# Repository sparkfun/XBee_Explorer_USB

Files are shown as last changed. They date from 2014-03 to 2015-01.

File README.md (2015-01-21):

SparkFun XBee Explorer USB
==========================

SparkFun XBee Explorer USB

[*SparkFun XBee Explorer USB (WRL-11812)*](https://www.sparkfun.com/products/11812)

This is a simple to use, USB to serial base unit for the Digi XBee line. 
This unit works with all XBee modules including the Series 1 and Series 2.5, standard and Pro version. 
Plug the unit into the XBee Explorer, attach a mini USB cable, 
and you will have direct access to the serial and programming pins on the XBee unit.
It has an FT231X USB-to-serial converter on board. 

Repository Contents
-------------------

* **/Hardware** - All Eagle design files (.brd, .sch)
* **/Production** - Test bed files and production panel files

Product Versions
----------------
* [WRL-08687](https://www.sparkfun.com/products/retired/8687)- Hardware version 1.5, with FT232 USB-to-serial converter. Retired

Version History
---------------
* [V_2.1](https://github.com/sparkfun/XBee_Explorer_USB/tree/V_2.1) - GitHub files version 2.1
* [V_1.5](https://github.com/sparkfun/XBee_Explorer_USB/tree/V_1.5) -- GitHub files version 1.5

License Information
-------------------
The hardware is released under [Creative Commons ShareAlike 4.0 International](https://creativecommons.org/licenses/by-sa/4.0/).

Distributed as-is; no warranty is given.

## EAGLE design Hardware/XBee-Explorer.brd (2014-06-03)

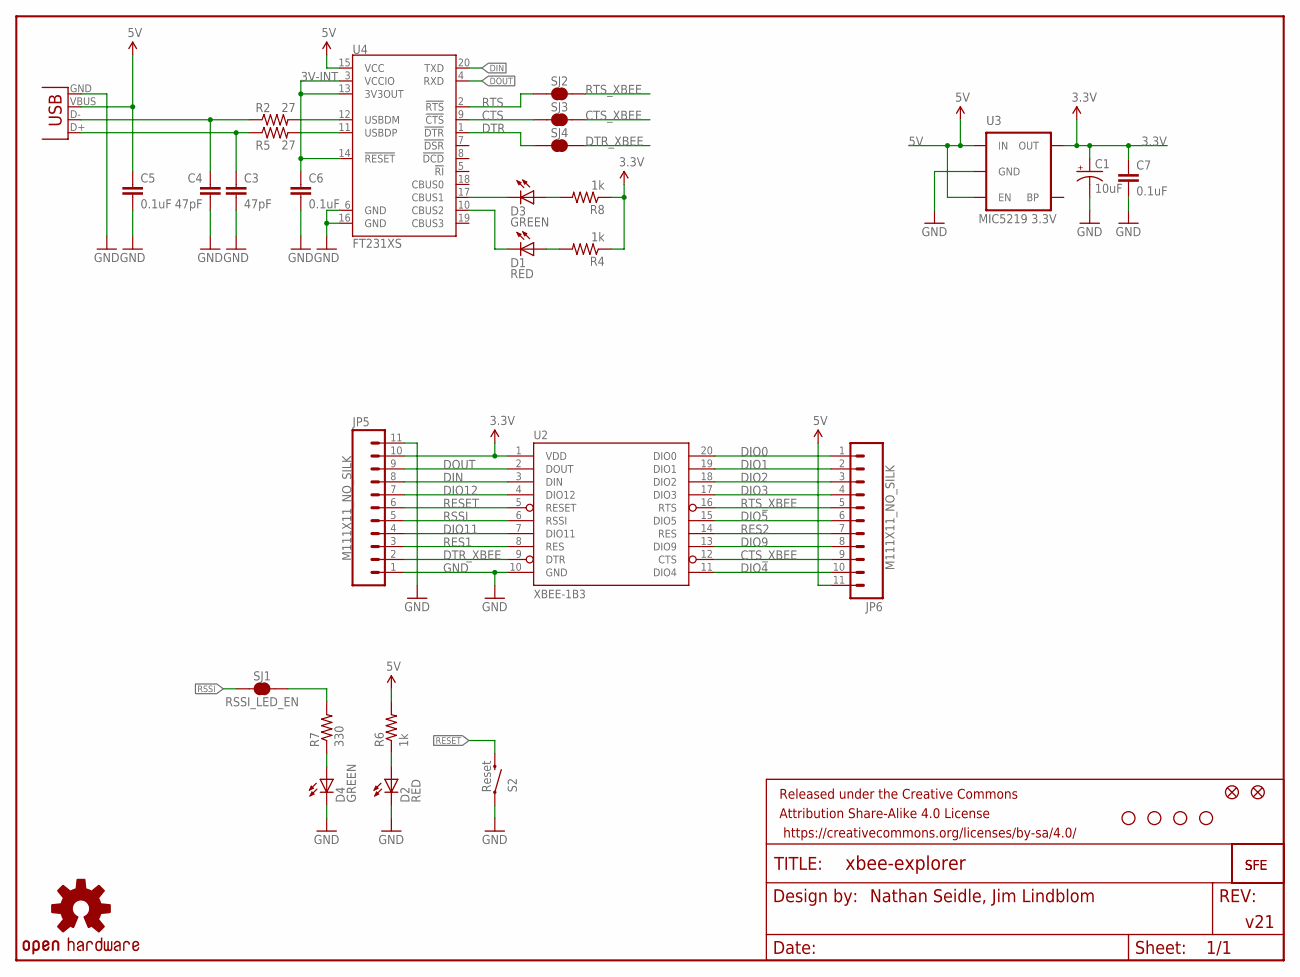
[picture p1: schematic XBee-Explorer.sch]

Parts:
C1: 10uF; EIA3216
C3, C4: 47pF; 0603-CAP
C5, C6, C7: 0.1uF; 0603-CAP
D1, D2: RED; LED-0603
D3, D4: GREEN; LED-0603
FRAME1: FRAME-LETTER; CREATIVE_COMMONS
JP1, JP4: FIDUCIAL1X2; FIDUCIAL-1X2
JP5, JP6: M111X11_NO_SILK; 1X11_NO_SILK
LOGO1: OSHW-LOGOS; OSHW-LOGO-S
R2, R5: 27; 0603-RES
R4, R6, R8: 1k; 0603-RES
R7: 330; 0603-RES
S2: Reset; TACTILE_SWITCH_SMD
SJ1: RSSI_LED_EN; SJ_2S-TRACE
SJ2: CTS_EN; SJ_2S-TRACE
SJ3: RTS_EN; SJ_2S-TRACE
SJ4: DTR; SJ_2S-TRACE
U2: XBEE-1B3; XBEE-SMD
U3: MIC5219 3.3V; SOT23-5
U4: FT231XS; SSOP20_L
U$1: LOGO-SFESK; SFE-LOGO-FLAME
U$4: LOGO-SFENEW; SFE-NEW-WEBLOGO
U$5, U$9, U$10, U$11: STAND-OFF
X1: USBSMD; USB-MINIB

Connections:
3.3V: C1.A (+), C7.1, JP5.10, R4.1, R8.1, U2.1 (VDD), U3.5 (OUT)
3V-INT: C6.1, U4.3 (VCCIO), U4.13 (3V3OUT), U4.14 (!RESET)
5V: C5.1, JP6.11, R6.2, U3.1 (IN), U3.3 (EN), U4.15 (VCC), X1.VBUS
CTS: SJ3.1, U4.9 (!CTS)
CTS_XBEE: JP6.9, SJ3.2, U2.12 (CTS)
DIN: JP5.8, U2.3 (DIN), U4.20 (TXD)
DIO0: JP6.1, U2.20 (DIO0)
DIO1: JP6.2, U2.19 (DIO1)
DIO2: JP6.3, U2.18 (DIO2)
DIO3: JP6.4, U2.17 (DIO3)
DIO4: JP6.10, U2.11 (DIO4)
DIO5: JP6.6, U2.15 (DIO5)
DIO9: JP6.8, U2.13 (DIO9)
DIO11: JP5.4, U2.7 (DIO11)
DIO12: JP5.7, U2.4 (DIO12)
DOUT: JP5.9, U2.2 (DOUT), U4.4 (RXD)
DTR: SJ4.1, U4.1 (!DTR)
DTR_XBEE: JP5.2, SJ4.2, U2.9 (DTR)
GND: C1.C (-), C3.2, C4.2, C5.2, C6.2, C7.2, D2.C, D4.C, JP5.1, JP5.11, S2.1, U2.10 (GND), U3.2 (GND), U4.6 (GND), U4.16 (GND), X1.GND
unnamed: D1.A, R4.2
unnamed: D4.A, R7.1
unnamed: C3.1, R5.1, X1.D+
unnamed: D3.A, R8.2
unnamed: C4.1, R2.1, X1.D-
unnamed: D3.C, U4.17 (CBUS1)
unnamed: R5.2, U4.11 (USBDP)
unnamed: R2.2, U4.12 (USBDM)
unnamed: R7.2, SJ1.2
unnamed: D2.A, R6.1
RES1: JP5.3, U2.8 (RES)
RES2: JP6.7, U2.14 (RES)
RESET: JP5.6, S2.3 (2), U2.5 (RESET)
RSSI: JP5.5, SJ1.1, U2.6 (RSSI)
RTS: SJ2.1, U4.2 (!RTS)
RTS_XBEE: JP6.5, SJ2.2, U2.16 (RTS)
TXLED: D1.C, U4.10 (CBUS2)

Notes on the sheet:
Nathan Seidle, Jim Lindblom
v21

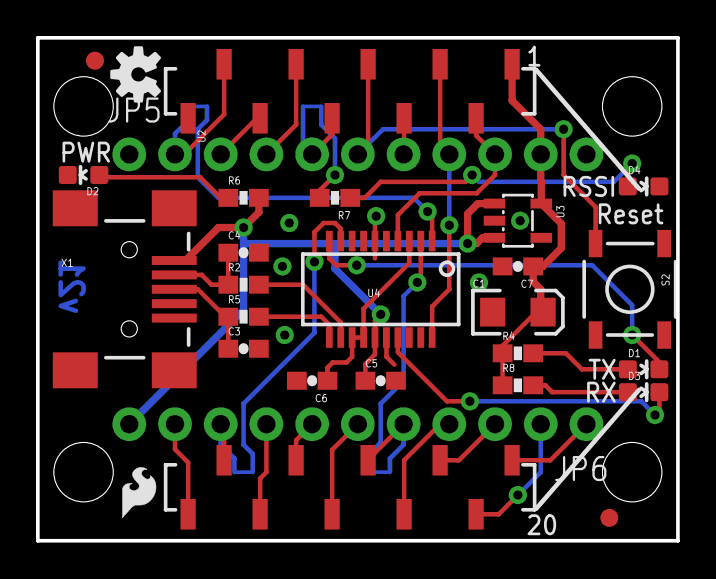
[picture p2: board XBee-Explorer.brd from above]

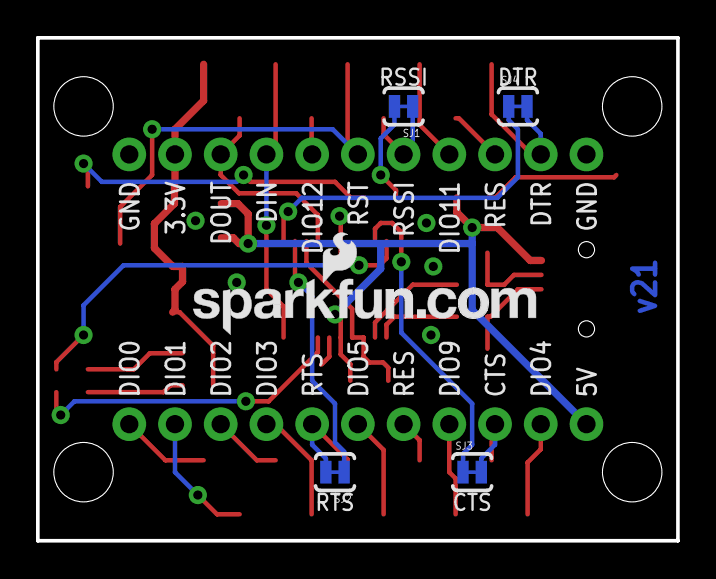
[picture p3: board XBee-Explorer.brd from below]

Board: 2 copper layers, 35.6 x 27.9 mm, 37 parts (5 on the bottom side), 36 nets.

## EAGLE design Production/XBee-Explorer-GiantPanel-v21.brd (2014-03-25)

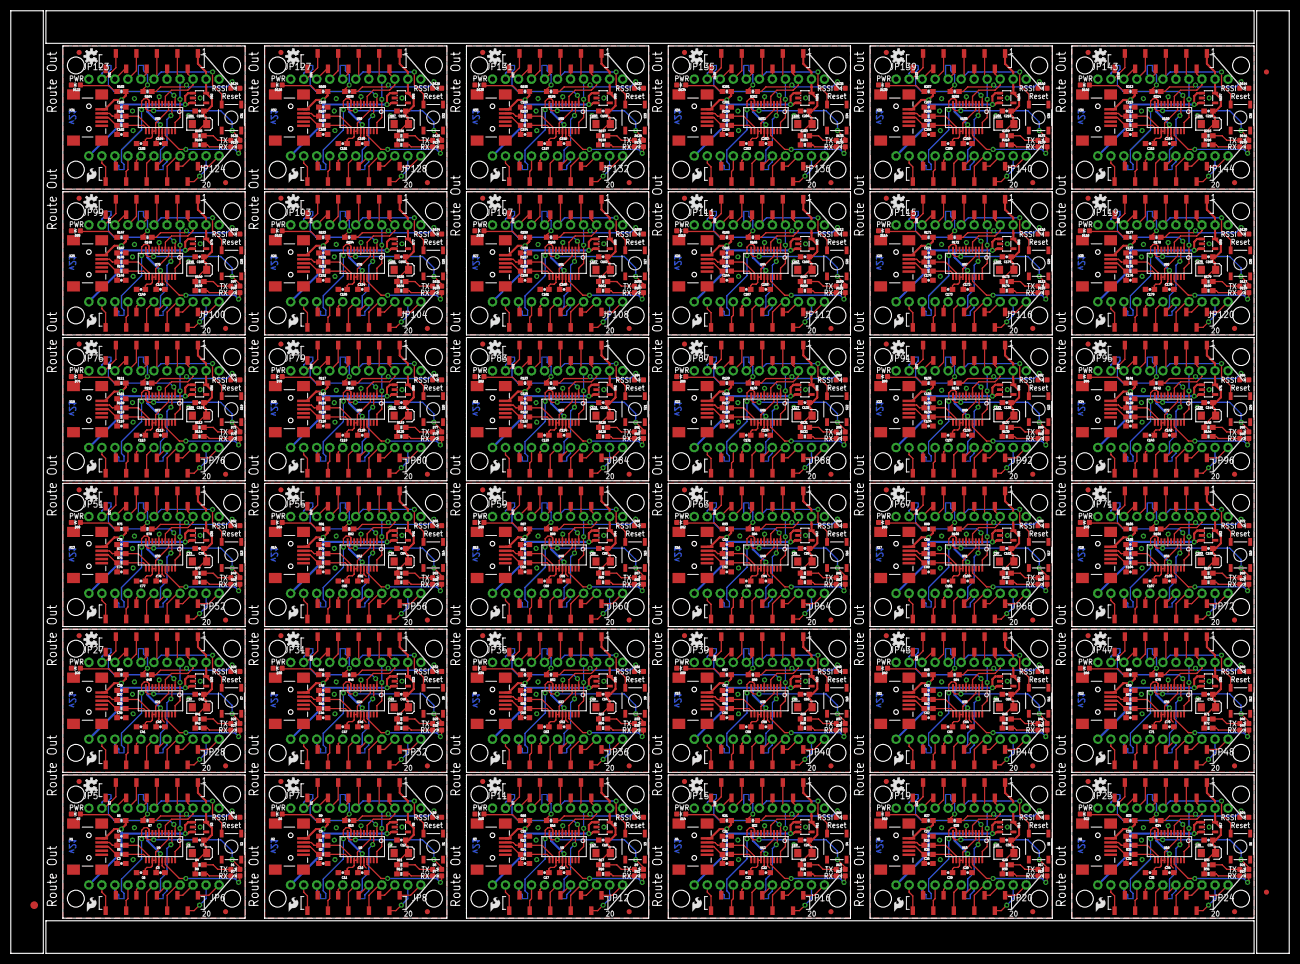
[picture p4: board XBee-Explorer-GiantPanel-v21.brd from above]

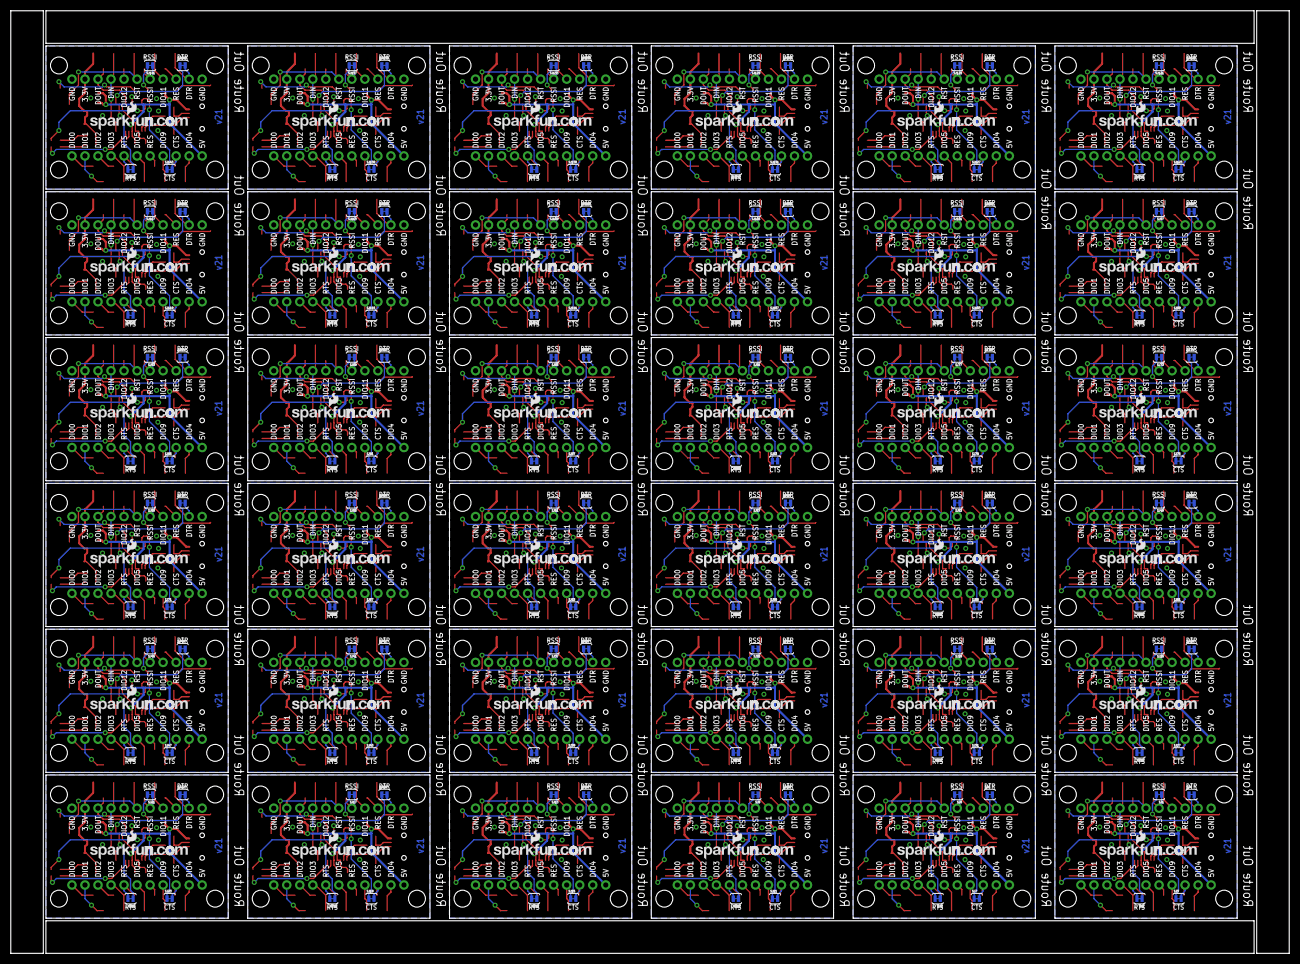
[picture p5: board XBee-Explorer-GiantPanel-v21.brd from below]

Board: 2 copper layers, 249.4 x 183.9 mm, 1299 parts (180 on the bottom side), 1296 nets.

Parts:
C1, C2, C13, C19, C25, C31, C37, C43, C49, C55, C61, C67, C73, C79, C85, C91, C97, C103, C109, C115, C121, C127, C133, C139, C145, C151, C157, C163, C169, C175, C181, C187, C193, C199, C205, C211: 10uF; EIA3216
C3, C4, C8, C9, C14, C15, C20, C21, C26, C27, C32, C33, C38, C39, C44, C45, C50, C51, C56, C57, C62, C63, C68, C69, C74, C75, C80, C81, C86, C87, C92, C93, C98, C99, C104, C105, C110, C111, C116, C117, C122, C123, C128, C129, C134, C135, C140, C141, C146, C147, C152, C153, C158, C159, C164, C165, C170, C171, C176, C177, C182, C183, C188, C189, C194, C195, C200, C201, C206, C207, C212, C213: 47pF; 0603-CAP
C5, C6, C7, C10, C11, C12, C16, C17, C18, C22, C23, C24, C28, C29, C30, C34, C35, C36, C40, C41, C42, C46, C47, C48, C52, C53, C54, C58, C59, C60, C64, C65, C66, C70, C71, C72, C76, C77, C78, C82, C83, C84, C88, C89, C90, C94, C95, C96, C100, C101, C102, C106, C107, C108, C112, C113, C114, C118, C119, C120, C124, C125, C126, C130, C131, C132, C136, C137, C138, C142, C143, C144, C148, C149, C150, C154, C155, C156, C160, C161, C162, C166, C167, C168, C172, C173, C174, C178, C179, C180, C184, C185, C186, C190, C191, C192, C196, C197, C198, C202, C203, C204, C208, C209, C210, C214, C215, C216: 0.1uF; 0603-CAP
D1, D2, D5, D6, D9, D10, D13, D14, D17, D18, D21, D22, D25, D26, D29, D30, D33, D34, D37, D38, D41, D42, D45, D46, D49, D50, D53, D54, D57, D58, D61, D62, D65, D66, D69, D70, D73, D74, D77, D78, D81, D82, D85, D86, D89, D90, D93, D94, D97, D98, D101, D102, D105, D106, D109, D110, D113, D114, D117, D118, D121, D122, D125, D126, D129, D130, D133, D134, D137, D138, D141, D142: RED; LED-0603
D3, D4, D7, D8, D11, D12, D15, D16, D19, D20, D23, D24, D27, D28, D31, D32, D35, D36, D39, D40, D43, D44, D47, D48, D51, D52, D55, D56, D59, D60, D63, D64, D67, D68, D71, D72, D75, D76, D79, D80, D83, D84, D87, D88, D91, D92, D95, D96, D99, D100, D103, D104, D107, D108, D111, D112, D115, D116, D119, D120, D123, D124, D127, D128, D131, D132, D135, D136, D139, D140, D143, D144: GREEN; LED-0603
E$1: FIDUCIAL-1.5X3
E$5, E$7: FIDUCIAL-1X2
JP1, JP2, JP3, JP4, JP9, JP10, JP13, JP14, JP17, JP18, JP21, JP22, JP25, JP26, JP29, JP30, JP33, JP34, JP37, JP38, JP41, JP42, JP45, JP46, JP49, JP50, JP53, JP54, JP57, JP58, JP61, JP62, JP65, JP66, JP69, JP70, JP73, JP74, JP77, JP78, JP81, JP82, JP85, JP86, JP89, JP90, JP93, JP94, JP97, JP98, JP101, JP102, JP105, JP106, JP109, JP110, JP113, JP114, JP117, JP118, JP121, JP122, JP125, JP126, JP129, JP130, JP133, JP134, JP137, JP138, JP141, JP142: FIDUCIAL1X2; FIDUCIAL-1X2
JP5, JP6, JP7, JP8, JP11, JP12, JP15, JP16, JP19, JP20, JP23, JP24, JP27, JP28, JP31, JP32, JP35, JP36, JP39, JP40, JP43, JP44, JP47, JP48, JP51, JP52, JP55, JP56, JP59, JP60, JP63, JP64, JP67, JP68, JP71, JP72, JP75, JP76, JP79, JP80, JP83, JP84, JP87, JP88, JP91, JP92, JP95, JP96, JP99, JP100, JP103, JP104, JP107, JP108, JP111, JP112, JP115, JP116, JP119, JP120, JP123, JP124, JP127, JP128, JP131, JP132, JP135, JP136, JP139, JP140, JP143, JP144: M111X11_NO_SILK; 1X11_NO_SILK
LOGO1, LOGO2, LOGO3, LOGO4, LOGO5, LOGO6, LOGO7, LOGO8, LOGO9, LOGO10, LOGO11, LOGO12, LOGO13, LOGO14, LOGO15, LOGO16, LOGO17, LOGO18, LOGO19, LOGO20, LOGO21, LOGO22, LOGO23, LOGO24, LOGO25, LOGO26, LOGO27, LOGO28, LOGO29, LOGO30, LOGO31, LOGO32, LOGO33, LOGO34, LOGO35, LOGO36: OSHW-LOGOS; OSHW-LOGO-S
R1, R2, R3, R5, R13, R14, R19, R20, R25, R26, R31, R32, R37, R38, R43, R44, R49, R50, R55, R56, R61, R62, R67, R68, R73, R74, R79, R80, R85, R86, R91, R92, R97, R98, R103, R104, R109, R110, R115, R116, R121, R122, R127, R128, R133, R134, R139, R140, R145, R146, R151, R152, R157, R158, R163, R164, R169, R170, R175, R176, R181, R182, R187, R188, R193, R194, R199, R200, R205, R206, R211, R212: 27; 0603-RES
R4, R6, R8, R9, R11, R12, R15, R17, R18, R21, R23, R24, R27, R29, R30, R33, R35, R36, R39, R41, R42, R45, R47, R48, R51, R53, R54, R57, R59, R60, R63, R65, R66, R69, R71, R72, R75, R77, R78, R81, R83, R84, R87, R89, R90, R93, R95, R96, R99, R101, R102, R105, R107, R108, R111, R113, R114, R117, R119, R120, R123, R125, R126, R129, R131, R132, R135, R137, R138, R141, R143, R144, R147, R149, R150, R153, R155, R156, R159, R161, R162, R165, R167, R168, R171, R173, R174, R177, R179, R180, R183, R185, R186, R189, R191, R192, R195, R197, R198, R201, R203, R204, R207, R209, R210, R213, R215, R216: 1k; 0603-RES
R7, R10, R16, R22, R28, R34, R40, R46, R52, R58, R64, R70, R76, R82, R88, R94, R100, R106, R112, R118, R124, R130, R136, R142, R148, R154, R160, R166, R172, R178, R184, R190, R196, R202, R208, R214: 330; 0603-RES
S1, S2, S3, S4, S5, S6, S7, S8, S9, S10, S11, S12, S13, S14, S15, S16, S17, S18, S19, S20, S21, S22, S23, S24, S25, S26, S27, S28, S29, S30, S31, S32, S33, S34, S35, S36: Reset; TACTILE_SWITCH_SMD
SJ1, SJ5, SJ9, SJ13, SJ17, SJ21, SJ25, SJ29, SJ33, SJ37, SJ41, SJ45, SJ49, SJ53, SJ57, SJ61, SJ65, SJ69, SJ73, SJ77, SJ81, SJ85, SJ89, SJ93, SJ97, SJ101, SJ105, SJ109, SJ113, SJ117, SJ121, SJ125, SJ129, SJ133, SJ137, SJ141: RSSI_LED_EN; SJ_2S-TRACE
SJ2, SJ8, SJ12, SJ16, SJ20, SJ24, SJ28, SJ32, SJ36, SJ40, SJ44, SJ48, SJ52, SJ56, SJ60, SJ64, SJ68, SJ72, SJ76, SJ80, SJ84, SJ88, SJ92, SJ96, SJ100, SJ104, SJ108, SJ112, SJ116, SJ120, SJ124, SJ128, SJ132, SJ136, SJ140, SJ144: CTS_EN; SJ_2S-TRACE
SJ3, SJ7, SJ11, SJ15, SJ19, SJ23, SJ27, SJ31, SJ35, SJ39, SJ43, SJ47, SJ51, SJ55, SJ59, SJ63, SJ67, SJ71, SJ75, SJ79, SJ83, SJ87, SJ91, SJ95, SJ99, SJ103, SJ107, SJ111, SJ115, SJ119, SJ123, SJ127, SJ131, SJ135, SJ139, SJ143: RTS_EN; SJ_2S-TRACE
SJ4, SJ6, SJ10, SJ14, SJ18, SJ22, SJ26, SJ30, SJ34, SJ38, SJ42, SJ46, SJ50, SJ54, SJ58, SJ62, SJ66, SJ70, SJ74, SJ78, SJ82, SJ86, SJ90, SJ94, SJ98, SJ102, SJ106, SJ110, SJ114, SJ118, SJ122, SJ126, SJ130, SJ134, SJ138, SJ142: DTR; SJ_2S-TRACE
U1, U2, U7, U10, U13, U16, U19, U22, U25, U28, U31, U34, U37, U40, U43, U46, U49, U52, U55, U58, U61, U64, U67, U70, U73, U76, U79, U82, U85, U88, U91, U94, U97, U100, U103, U106: XBEE-1B3; XBEE-SMD
U3, U5, U8, U11, U14, U17, U20, U23, U26, U29, U32, U35, U38, U41, U44, U47, U50, U53, U56, U59, U62, U65, U68, U71, U74, U77, U80, U83, U86, U89, U92, U95, U98, U101, U104, U107: MIC5205 3.3V; SOT23-5
U4, U6, U9, U12, U15, U18, U21, U24, U27, U30, U33, U36, U39, U42, U45, U48, U51, U54, U57, U60, U63, U66, U69, U72, U75, U78, U81, U84, U87, U90, U93, U96, U99, U102, U105, U108: FT231XS; SSOP20_L
U$1, U$2, U$13, U$19, U$25, U$31, U$37, U$43, U$49, U$55, U$61, U$67, U$73, U$79, U$85, U$91, U$97, U$103, U$109, U$115, U$121, U$127, U$133, U$139, U$145, U$151, U$157, U$163, U$169, U$175, U$181, U$187, U$193, U$199, U$205, U$211: LOGO-SFESK; SFE-LOGO-FLAME
U$3, U$4, U$14, U$20, U$26, U$32, U$38, U$44, U$50, U$56, U$62, U$68, U$74, U$80, U$86, U$92, U$98, U$104, U$110, U$116, U$122, U$128, U$134, U$140, U$146, U$152, U$158, U$164, U$170, U$176, U$182, U$188, U$194, U$200, U$206, U$212: LOGO-SFENEW; SFE-NEW-WEBLOGO
U$5, U$6, U$7, U$8, U$9, U$10, U$11, U$12, U$15, U$16, U$17, U$18, U$21, U$22, U$23, U$24, U$27, U$28, U$29, U$30, U$33, U$34, U$35, U$36, U$39, U$40, U$41, U$42, U$45, U$46, U$47, U$48, U$51, U$52, U$53, U$54, U$57, U$58, U$59, U$60, U$63, U$64, U$65, U$66, U$69, U$70, U$71, U$72, U$75, U$76, U$77, U$78, U$81, U$82, U$83, U$84, U$87, U$88, U$89, U$90, U$93, U$94, U$95, U$96, U$99, U$100, U$101, U$102, U$105, U$106, U$107, U$108, U$111, U$112, U$113, U$114, U$117, U$118, U$119, U$120, U$123, U$124, U$125, U$126, U$129, U$130, U$131, U$132, U$135, U$136, U$137, U$138, U$141, U$142, U$143, U$144, U$147, U$148, U$149, U$150, U$153, U$154, U$155, U$156, U$159, U$160, U$161, U$162, U$165, U$166, U$167, U$168, U$171, U$172, U$173, U$174, U$177, U$178, U$179, U$180, U$183, U$184, U$185, U$186, U$189, U$190, U$191, U$192, U$195, U$196, U$197, U$198, U$201, U$202, U$203, U$204, U$207, U$208, U$209, U$210, U$213, U$214, U$215, U$216: STAND-OFF
X1, X2, X3, X4, X5, X6, X7, X8, X9, X10, X11, X12, X13, X14, X15, X16, X17, X18, X19, X20, X21, X22, X23, X24, X25, X26, X27, X28, X29, X30, X31, X32, X33, X34, X35, X36: USBSMD; USB-MINIB

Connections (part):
3.3V: C1.A, C7.1, JP5.10, R4.1, R8.1, U2.1, U3.5
3.3V1: C2.A, C12.1, JP7.10, R11.1, R12.1, U1.1, U5.5
3.3V2: C13.A, C18.1, JP11.10, R17.1, R18.1, U7.1, U8.5
3.3V3: C19.A, C24.1, JP15.10, R23.1, R24.1, U10.1, U11.5
3.3V4: C25.A, C30.1, JP19.10, R29.1, R30.1, U13.1, U14.5
3.3V5: C31.A, C36.1, JP23.10, R35.1, R36.1, U16.1, U17.5
3.3V6: C37.A, C42.1, JP27.10, R41.1, R42.1, U19.1, U20.5
3.3V7: C43.A, C48.1, JP31.10, R47.1, R48.1, U22.1, U23.5
3.3V8: C49.A, C54.1, JP35.10, R53.1, R54.1, U25.1, U26.5
3.3V9: C55.A, C60.1, JP39.10, R59.1, R60.1, U28.1, U29.5
3.3V10: C61.A, C66.1, JP43.10, R65.1, R66.1, U31.1, U32.5
3.3V11: C67.A, C72.1, JP47.10, R71.1, R72.1, U34.1, U35.5
3.3V12: C73.A, C78.1, JP51.10, R77.1, R78.1, U37.1, U38.5
3.3V13: C79.A, C84.1, JP55.10, R83.1, R84.1, U40.1, U41.5
3.3V14: C85.A, C90.1, JP59.10, R89.1, R90.1, U43.1, U44.5
3.3V15: C91.A, C96.1, JP63.10, R95.1, R96.1, U46.1, U47.5
3.3V16: C97.A, C102.1, JP67.10, R101.1, R102.1, U49.1, U50.5
3.3V17: C103.A, C108.1, JP71.10, R107.1, R108.1, U52.1, U53.5
3.3V18: C109.A, C114.1, JP75.10, R113.1, R114.1, U55.1, U56.5
3.3V19: C115.A, C120.1, JP79.10, R119.1, R120.1, U58.1, U59.5
3.3V20: C121.A, C126.1, JP83.10, R125.1, R126.1, U61.1, U62.5
3.3V21: C127.A, C132.1, JP87.10, R131.1, R132.1, U64.1, U65.5
3.3V22: C133.A, C138.1, JP91.10, R137.1, R138.1, U67.1, U68.5
3.3V23: C139.A, C144.1, JP95.10, R143.1, R144.1, U70.1, U71.5
3.3V24: C145.A, C150.1, JP99.10, R149.1, R150.1, U73.1, U74.5
3.3V25: C151.A, C156.1, JP103.10, R155.1, R156.1, U76.1, U77.5
3.3V26: C157.A, C162.1, JP107.10, R161.1, R162.1, U79.1, U80.5
3.3V27: C163.A, C168.1, JP111.10, R167.1, R168.1, U82.1, U83.5
3.3V28: C169.A, C174.1, JP115.10, R173.1, R174.1, U85.1, U86.5
3.3V29: C175.A, C180.1, JP119.10, R179.1, R180.1, U88.1, U89.5
3.3V30: C181.A, C186.1, JP123.10, R185.1, R186.1, U91.1, U92.5
3.3V31: C187.A, C192.1, JP127.10, R191.1, R192.1, U94.1, U95.5
3.3V32: C193.A, C198.1, JP131.10, R197.1, R198.1, U97.1, U98.5
3.3V33: C199.A, C204.1, JP135.10, R203.1, R204.1, U100.1, U101.5
3.3V34: C205.A, C210.1, JP139.10, R209.1, R210.1, U103.1, U104.5
3.3V35: C211.A, C216.1, JP143.10, R215.1, R216.1, U106.1, U107.5
3V-INT: C6.1, U4.3, U4.13, U4.14
3V-INT1: C11.1, U6.3, U6.13, U6.14
3V-INT2: C17.1, U9.3, U9.13, U9.14
3V-INT3: C23.1, U12.3, U12.13, U12.14
3V-INT4: C29.1, U15.3, U15.13, U15.14
3V-INT5: C35.1, U18.3, U18.13, U18.14
3V-INT6: C41.1, U21.3, U21.13, U21.14
3V-INT7: C47.1, U24.3, U24.13, U24.14
3V-INT8: C53.1, U27.3, U27.13, U27.14
3V-INT9: C59.1, U30.3, U30.13, U30.14
3V-INT10: C65.1, U33.3, U33.13, U33.14
3V-INT11: C71.1, U36.3, U36.13, U36.14
3V-INT12: C77.1, U39.3, U39.13, U39.14
3V-INT13: C83.1, U42.3, U42.13, U42.14
3V-INT14: C89.1, U45.3, U45.13, U45.14
3V-INT15: C95.1, U48.3, U48.13, U48.14
3V-INT16: C101.1, U51.3, U51.13, U51.14
3V-INT17: C107.1, U54.3, U54.13, U54.14
3V-INT18: C113.1, U57.3, U57.13, U57.14
3V-INT19: C119.1, U60.3, U60.13, U60.14
3V-INT20: C125.1, U63.3, U63.13, U63.14
3V-INT21: C131.1, U66.3, U66.13, U66.14
3V-INT22: C137.1, U69.3, U69.13, U69.14
3V-INT23: C143.1, U72.3, U72.13, U72.14
3V-INT24: C149.1, U75.3, U75.13, U75.14
3V-INT25: C155.1, U78.3, U78.13, U78.14
3V-INT26: C161.1, U81.3, U81.13, U81.14
3V-INT27: C167.1, U84.3, U84.13, U84.14
3V-INT28: C173.1, U87.3, U87.13, U87.14
3V-INT29: C179.1, U90.3, U90.13, U90.14
3V-INT30: C185.1, U93.3, U93.13, U93.14
3V-INT31: C191.1, U96.3, U96.13, U96.14
3V-INT32: C197.1, U99.3, U99.13, U99.14
3V-INT33: C203.1, U102.3, U102.13, U102.14
3V-INT34: C209.1, U105.3, U105.13, U105.14
3V-INT35: C215.1, U108.3, U108.13, U108.14
5V: C5.1, JP6.11, R6.2, U3.1, U3.3, U4.15, X1.VBUS
5V1: C10.1, JP8.11, R9.2, U5.1, U5.3, U6.15, X2.VBUS
5V2: C16.1, JP12.11, R15.2, U8.1, U8.3, U9.15, X3.VBUS
5V3: C22.1, JP16.11, R21.2, U11.1, U11.3, U12.15, X4.VBUS
5V4: C28.1, JP20.11, R27.2, U14.1, U14.3, U15.15, X5.VBUS
5V5: C34.1, JP24.11, R33.2, U17.1, U17.3, U18.15, X6.VBUS
5V6: C40.1, JP28.11, R39.2, U20.1, U20.3, U21.15, X7.VBUS
5V7: C46.1, JP32.11, R45.2, U23.1, U23.3, U24.15, X8.VBUS
5V8: C52.1, JP36.11, R51.2, U26.1, U26.3, U27.15, X9.VBUS
5V9: C58.1, JP40.11, R57.2, U29.1, U29.3, U30.15, X10.VBUS
5V10: C64.1, JP44.11, R63.2, U32.1, U32.3, U33.15, X11.VBUS
5V11: C70.1, JP48.11, R69.2, U35.1, U35.3, U36.15, X12.VBUS
5V12: C76.1, JP52.11, R75.2, U38.1, U38.3, U39.15, X13.VBUS
5V13: C82.1, JP56.11, R81.2, U41.1, U41.3, U42.15, X14.VBUS
5V14: C88.1, JP60.11, R87.2, U44.1, U44.3, U45.15, X15.VBUS
5V15: C94.1, JP64.11, R93.2, U47.1, U47.3, U48.15, X16.VBUS
5V16: C100.1, JP68.11, R99.2, U50.1, U50.3, U51.15, X17.VBUS
5V17: C106.1, JP72.11, R105.2, U53.1, U53.3, U54.15, X18.VBUS
5V18: C112.1, JP76.11, R111.2, U56.1, U56.3, U57.15, X19.VBUS
5V19: C118.1, JP80.11, R117.2, U59.1, U59.3, U60.15, X20.VBUS
5V20: C124.1, JP84.11, R123.2, U62.1, U62.3, U63.15, X21.VBUS
5V21: C130.1, JP88.11, R129.2, U65.1, U65.3, U66.15, X22.VBUS
5V22: C136.1, JP92.11, R135.2, U68.1, U68.3, U69.15, X23.VBUS
5V23: C142.1, JP96.11, R141.2, U71.1, U71.3, U72.15, X24.VBUS
5V24: C148.1, JP100.11, R147.2, U74.1, U74.3, U75.15, X25.VBUS
5V25: C154.1, JP104.11, R153.2, U77.1, U77.3, U78.15, X26.VBUS
5V26: C160.1, JP108.11, R159.2, U80.1, U80.3, U81.15, X27.VBUS
5V27: C166.1, JP112.11, R165.2, U83.1, U83.3, U84.15, X28.VBUS
5V28: C172.1, JP116.11, R171.2, U86.1, U86.3, U87.15, X29.VBUS
5V29: C178.1, JP120.11, R177.2, U89.1, U89.3, U90.15, X30.VBUS
5V30: C184.1, JP124.11, R183.2, U92.1, U92.3, U93.15, X31.VBUS
5V31: C190.1, JP128.11, R189.2, U95.1, U95.3, U96.15, X32.VBUS
5V32: C196.1, JP132.11, R195.2, U98.1, U98.3, U99.15, X33.VBUS
5V33: C202.1, JP136.11, R201.2, U101.1, U101.3, U102.15, X34.VBUS
5V34: C208.1, JP140.11, R207.2, U104.1, U104.3, U105.15, X35.VBUS
5V35: C214.1, JP144.11, R213.2, U107.1, U107.3, U108.15, X36.VBUS
CTS: SJ3.1, U4.9
CTS1: SJ7.1, U6.9
CTS2: SJ11.1, U9.9
CTS3: SJ15.1, U12.9
CTS4: SJ19.1, U15.9
CTS5: SJ23.1, U18.9
CTS6: SJ27.1, U21.9
CTS7: SJ31.1, U24.9
CTS8: SJ35.1, U27.9
CTS9: SJ39.1, U30.9
CTS10: SJ43.1, U33.9
CTS11: SJ47.1, U36.9
CTS12: SJ51.1, U39.9
CTS13: SJ55.1, U42.9
CTS14: SJ59.1, U45.9
CTS15: SJ63.1, U48.9
CTS16: SJ67.1, U51.9
CTS17: SJ71.1, U54.9
CTS18: SJ75.1, U57.9
CTS19: SJ79.1, U60.9
CTS20: SJ83.1, U63.9
CTS21: SJ87.1, U66.9
CTS22: SJ91.1, U69.9
CTS23: SJ95.1, U72.9
CTS24: SJ99.1, U75.9
CTS25: SJ103.1, U78.9
CTS26: SJ107.1, U81.9
CTS27: SJ111.1, U84.9
CTS28: SJ115.1, U87.9
CTS29: SJ119.1, U90.9
CTS30: SJ123.1, U93.9
CTS31: SJ127.1, U96.9
CTS32: SJ131.1, U99.9
CTS33: SJ135.1, U102.9
CTS34: SJ139.1, U105.9
CTS35: SJ143.1, U108.9
CTS_XBEE: JP6.9, SJ3.2, U2.12
CTS_XBEE1: JP8.9, SJ7.2, U1.12
CTS_XBEE2: JP12.9, SJ11.2, U7.12
CTS_XBEE3: JP16.9, SJ15.2, U10.12
CTS_XBEE4: JP20.9, SJ19.2, U13.12
CTS_XBEE5: JP24.9, SJ23.2, U16.12
CTS_XBEE6: JP28.9, SJ27.2, U19.12
CTS_XBEE7: JP32.9, SJ31.2, U22.12
CTS_XBEE8: JP36.9, SJ35.2, U25.12
CTS_XBEE9: JP40.9, SJ39.2, U28.12
CTS_XBEE10: JP44.9, SJ43.2, U31.12
CTS_XBEE11: JP48.9, SJ47.2, U34.12
CTS_XBEE12: JP52.9, SJ51.2, U37.12
CTS_XBEE13: JP56.9, SJ55.2, U40.12
CTS_XBEE14: JP60.9, SJ59.2, U43.12
CTS_XBEE15: JP64.9, SJ63.2, U46.12
CTS_XBEE16: JP68.9, SJ67.2, U49.12
CTS_XBEE17: JP72.9, SJ71.2, U52.12
CTS_XBEE18: JP76.9, SJ75.2, U55.12
CTS_XBEE19: JP80.9, SJ79.2, U58.12
CTS_XBEE20: JP84.9, SJ83.2, U61.12
CTS_XBEE21: JP88.9, SJ87.2, U64.12
CTS_XBEE22: JP92.9, SJ91.2, U67.12
CTS_XBEE23: JP96.9, SJ95.2, U70.12
CTS_XBEE24: JP100.9, SJ99.2, U73.12
CTS_XBEE25: JP104.9, SJ103.2, U76.12
CTS_XBEE26: JP108.9, SJ107.2, U79.12
CTS_XBEE27: JP112.9, SJ111.2, U82.12
CTS_XBEE28: JP116.9, SJ115.2, U85.12
CTS_XBEE29: JP120.9, SJ119.2, U88.12
CTS_XBEE30: JP124.9, SJ123.2, U91.12
CTS_XBEE31: JP128.9, SJ127.2, U94.12
CTS_XBEE32: JP132.9, SJ131.2, U97.12
CTS_XBEE33: JP136.9, SJ135.2, U100.12
CTS_XBEE34: JP140.9, SJ139.2, U103.12
CTS_XBEE35: JP144.9, SJ143.2, U106.12
DIN: JP5.8, U2.3, U4.20
DIN1: JP7.8, U1.3, U6.20
DIN2: JP11.8, U7.3, U9.20
DIN3: JP15.8, U10.3, U12.20
DIN4: JP19.8, U13.3, U15.20
DIN5: JP23.8, U16.3, U18.20
DIN6: JP27.8, U19.3, U21.20
DIN7: JP31.8, U22.3, U24.20
DIN8: JP35.8, U25.3, U27.20
DIN9: JP39.8, U28.3, U30.20
DIN10: JP43.8, U31.3, U33.20
DIN11: JP47.8, U34.3, U36.20
DIN12: JP51.8, U37.3, U39.20
DIN13: JP55.8, U40.3, U42.20
DIN14: JP59.8, U43.3, U45.20
DIN15: JP63.8, U46.3, U48.20
DIN16: JP67.8, U49.3, U51.20
DIN17: JP71.8, U52.3, U54.20
DIN18: JP75.8, U55.3, U57.20
DIN19: JP79.8, U58.3, U60.20
DIN20: JP83.8, U61.3, U63.20
DIN21: JP87.8, U64.3, U66.20
DIN22: JP91.8, U67.3, U69.20
DIN23: JP95.8, U70.3, U72.20
DIN24: JP99.8, U73.3, U75.20
DIN25: JP103.8, U76.3, U78.20
DIN26: JP107.8, U79.3, U81.20
DIN27: JP111.8, U82.3, U84.20
DIN28: JP115.8, U85.3, U87.20
DIN29: JP119.8, U88.3, U90.20
DIN30: JP123.8, U91.3, U93.20
DIN31: JP127.8, U94.3, U96.20
DIN32: JP131.8, U97.3, U99.20
DIN33: JP135.8, U100.3, U102.20
DIN34: JP139.8, U103.3, U105.20
DIN35: JP143.8, U106.3, U108.20
DIO0: JP6.1, U2.20
DIO1: JP6.2, U2.19
DIO2: JP6.3, U2.18
DIO3: JP6.4, U2.17
DIO4: JP6.10, U2.11
DIO5: JP6.6, U2.15
DIO6: JP8.10, U1.11
DIO7: JP8.8, U1.13
DIO8: JP8.6, U1.15
DIO9: JP6.8, U2.13
DIO10: JP8.4, U1.17
DIO11: JP5.4, U2.7
DIO12: JP5.7, U2.4
DIO13: JP8.3, U1.18
DIO14: JP8.2, U1.19
DIO15: JP8.1, U1.20
DIO16: JP7.4, U1.7
DIO17: JP7.7, U1.4
DIO18: JP12.10, U7.11
DIO19: JP12.8, U7.13
DIO20: JP12.6, U7.15
DIO21: JP12.4, U7.17
DIO22: JP12.3, U7.18
DIO23: JP12.2, U7.19
DIO24: JP12.1, U7.20
DIO25: JP11.4, U7.7
DIO26: JP11.7, U7.4
DIO27: JP16.10, U10.11
DIO28: JP16.8, U10.13
DIO29: JP16.6, U10.15
DIO30: JP16.4, U10.17
DIO31: JP16.3, U10.18
DIO32: JP16.2, U10.19
DIO33: JP16.1, U10.20
DIO34: JP15.4, U10.7
DIO35: JP15.7, U10.4
DIO36: JP20.10, U13.11
DIO37: JP20.8, U13.13
DIO38: JP20.6, U13.15
DIO39: JP20.4, U13.17
DIO40: JP20.3, U13.18
DIO41: JP20.2, U13.19
DIO42: JP20.1, U13.20
DIO43: JP19.4, U13.7
DIO44: JP19.7, U13.4
DIO45: JP24.10, U16.11
DIO46: JP24.8, U16.13
DIO47: JP24.6, U16.15
DIO48: JP24.4, U16.17
DIO49: JP24.3, U16.18
DIO50: JP24.2, U16.19
DIO51: JP24.1, U16.20
DIO52: JP23.4, U16.7
DIO53: JP23.7, U16.4
DIO54: JP28.10, U19.11
DIO55: JP28.8, U19.13
DIO56: JP28.6, U19.15
DIO57: JP28.4, U19.17
DIO58: JP28.3, U19.18
DIO59: JP28.2, U19.19
DIO60: JP28.1, U19.20
DIO61: JP27.4, U19.7
DIO62: JP27.7, U19.4
DIO63: JP32.10, U22.11
DIO64: JP32.8, U22.13
DIO65: JP32.6, U22.15
DIO66: JP32.4, U22.17
DIO67: JP32.3, U22.18
DIO68: JP32.2, U22.19
DIO69: JP32.1, U22.20
DIO70: JP31.4, U22.7
DIO71: JP31.7, U22.4
DIO72: JP36.10, U25.11
DIO73: JP36.8, U25.13
DIO74: JP36.6, U25.15
DIO75: JP36.4, U25.17
DIO76: JP36.3, U25.18
DIO77: JP36.2, U25.19
DIO78: JP36.1, U25.20
DIO79: JP35.4, U25.7
DIO80: JP35.7, U25.4
DIO81: JP40.10, U28.11
DIO82: JP40.8, U28.13
DIO83: JP40.6, U28.15
DIO84: JP40.4, U28.17
DIO85: JP40.3, U28.18
DIO86: JP40.2, U28.19
DIO87: JP40.1, U28.20
DIO88: JP39.4, U28.7
DIO89: JP39.7, U28.4
DIO90: JP44.10, U31.11
DIO91: JP44.8, U31.13
DIO92: JP44.6, U31.15
DIO93: JP44.4, U31.17
DIO94: JP44.3, U31.18
DIO95: JP44.2, U31.19
DIO96: JP44.1, U31.20
DIO97: JP43.4, U31.7
DIO98: JP43.7, U31.4
DIO99: JP48.10, U34.11
DIO100: JP48.8, U34.13
DIO101: JP48.6, U34.15
DIO102: JP48.4, U34.17
DIO103: JP48.3, U34.18
DIO104: JP48.2, U34.19
DIO105: JP48.1, U34.20
DIO106: JP47.4, U34.7
DIO107: JP47.7, U34.4
DIO108: JP52.10, U37.11
DIO109: JP52.8, U37.13
DIO110: JP52.6, U37.15
DIO111: JP52.4, U37.17
DIO112: JP52.3, U37.18
DIO113: JP52.2, U37.19
DIO114: JP52.1, U37.20
DIO115: JP51.4, U37.7
DIO116: JP51.7, U37.4
DIO117: JP56.10, U40.11
DIO118: JP56.8, U40.13
DIO119: JP56.6, U40.15
DIO120: JP56.4, U40.17
DIO121: JP56.3, U40.18
DIO122: JP56.2, U40.19
DIO123: JP56.1, U40.20
DIO124: JP55.4, U40.7
DIO125: JP55.7, U40.4
DIO126: JP60.10, U43.11
DIO127: JP60.8, U43.13
DIO128: JP60.6, U43.15
DIO129: JP60.4, U43.17
DIO130: JP60.3, U43.18
DIO131: JP60.2, U43.19
DIO132: JP60.1, U43.20
DIO133: JP59.4, U43.7
DIO134: JP59.7, U43.4
DIO135: JP64.10, U46.11
DIO136: JP64.8, U46.13
DIO137: JP64.6, U46.15
DIO138: JP64.4, U46.17
DIO139: JP64.3, U46.18
DIO140: JP64.2, U46.19
DIO141: JP64.1, U46.20
DIO142: JP63.4, U46.7
DIO143: JP63.7, U46.4
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

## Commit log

2013-03-22 Dongle initial commit (v13)
    This version has an SMD USB connector and an FT232RL.
    Updated Readme.
    [XBee-Explorer-Dongle.brd, XBee-Explorer-Dongle.sch]
2013-03-22 Explorer initial commit (v15)
    This is the currently live version of the XBee USB Explorer. It uses an
    FT232RL and has smaller annular rings.
    [XBee-Explorer.brd, XBee-Explorer.sch]
2013-03-22 XBee Explorer using FT231X
    Transitioning from the FT232RL to the FT231X.
    Updated all resistors and capacitor packages. Now using 0603 footprints
    for 0603 parts!
    Rearranged some parts on the layout (mostly VReg circuitry).
    Moved current limiting resistor for RSSI LED.
    [XBee-Explorer.brd, XBee-Explorer.sch]
2013-03-22 XBee Dongle transition to FT231X
    FT231X replaces the FT232RL.
    Additional components added (R2, R5, C3, C4).
    Updated all resistor and capacitor packages to 0603 footprints.
    Rearranged Vreg circuit layout.
    [XBee-Explorer-Dongle.brd, XBee-Explorer-Dongle.sch]
2013-04-04 Spaced out resistors and capacitors a tad
    [XBee-Explorer-Dongle.brd, XBee-Explorer.brd]
2013-12-02 Added jumper to disconnect RSSI LED, moved silk
    [XBee-Explorer-Dongle.brd, XBee-Explorer-Dongle.sch, XBee-Explorer.brd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]
2013-12-05 Adding reset button, jumpers on UART ctrl lines
    Reset button required moving LEDs around.
    Adding jumpers on DTR, CTS, and RTS because they're not present on some
    XBee compatible boards. Those pins can be used as GPIOs.
    [XBee-Explorer-Dongle.brd, XBee-Explorer-Dongle.sch, XBee-Explorer.brd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]
2014-03-13 Increasing fiducial size and LED footprint
    [XBee-Explorer-Dongle.brd, XBee-Explorer-Dongle.sch, XBee-Explorer.brd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]
2014-03-14 created giant panel
    [XBee-Explorer-Dongle-GiantPanel-v21.brd]
2014-03-25 Created USB Giant Panel
    [XBee-Explorer-GiantPanel-v21.brd]
2014-04-08 Moving USB connector back a bit to hold in place
    [XBee-Explorer-Dongle.brd, XBee-Explorer-Dongle.sch]
2014-04-08 re-created dongle giant panel
    [XBee-Explorer-Dongle-GiantPanel-v21.brd]
2014-06-02 Updating USB dongle connector to use locking fp
    [XBee-Explorer-Dongle.brd, XBee-Explorer-Dongle.sch]
2014-06-02 deleted panel v21, created panel v22
    [XBee-Explorer-Dongle-GiantPanel-v21.brd, XBee-Explorer-Dongle-GiantPanel-v22.brd]
2014-06-03 Updating VREG part information
    [XBee-Explorer-Dongle.brd, XBee-Explorer-Dongle.sch]
2014-06-03 Updating VREG part info on explorer
    [XBee-Explorer.brd, XBee-Explorer.sch]
2015-01-21 Deleting dongle files
    [XBee-Explorer-Dongle-GiantPanel-v22.brd, XBee-Explorer-Dongle.brd, XBee-Explorer-Dongle.sch]
2015-01-21 Updating README, modifying directory names.
    [XBee-Explorer-GiantPanel-v21.brd, XBee-Explorer.brd, XBee-Explorer.sch]

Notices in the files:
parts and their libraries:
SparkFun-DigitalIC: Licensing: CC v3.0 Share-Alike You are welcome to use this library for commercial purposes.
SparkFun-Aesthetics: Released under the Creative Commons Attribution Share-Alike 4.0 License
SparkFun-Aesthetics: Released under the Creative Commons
